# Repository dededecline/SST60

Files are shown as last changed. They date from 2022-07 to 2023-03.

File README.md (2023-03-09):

# SST60

## Hotswap
Looking for hotswap? See [here](https://github.com/dededecline/SST60/tree/main/Hotswap)

## Fully open source multi-layout 60% PCB
Render1
Render2
<sub> renders outdated, using the old outline. </sub>

## Layout support
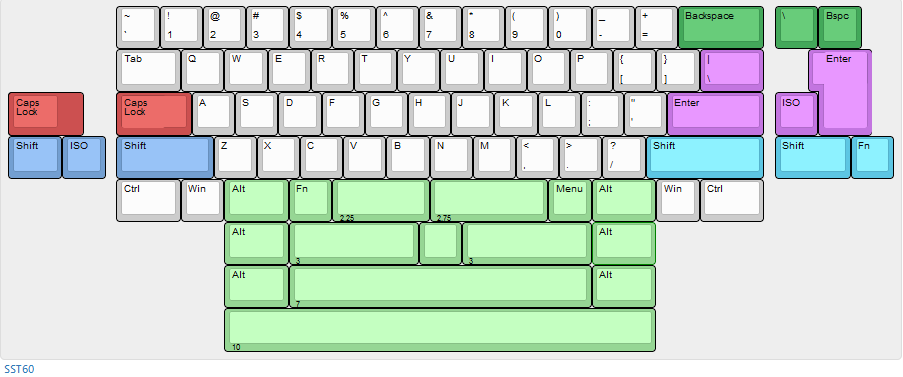
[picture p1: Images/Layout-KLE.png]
KLE


## Features
- RGB Underglow
- RP2040 processor
- MX and Alps compatible
- Indicator light positions for Caps Lock and Esc
- Standard tray mount support
- Gummy O-Ring support (Bakenko, ogre, etc. anything that h60 supports, this does too.)
- USB-C or Unified Daughterboard (or equivalent with the same pinout)
- Overcurrent and ESD protection
- Flex meme cuts

## ***DISCLAIMER***
This PCB has been tested and confirmed to work properly. The members of the PCB development team are not liable if you end up with a non-functional pcb. Order at your own risk. Support will not be provided but pull requests will be reviewed and possibly accepted.

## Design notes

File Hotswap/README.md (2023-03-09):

# SST60HS

## Fully open source multi-layout 60% PCB
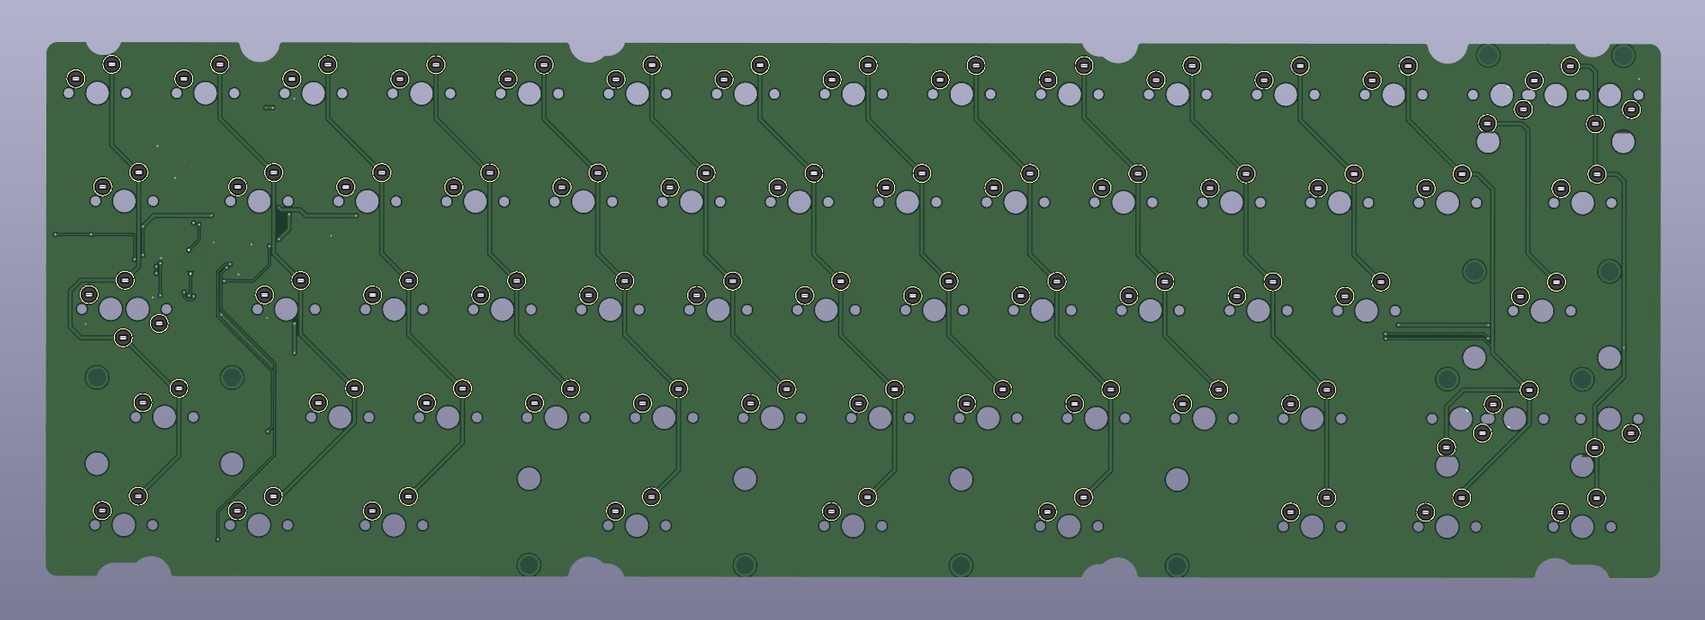
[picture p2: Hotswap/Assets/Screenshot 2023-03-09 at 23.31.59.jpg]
render


## Layout support
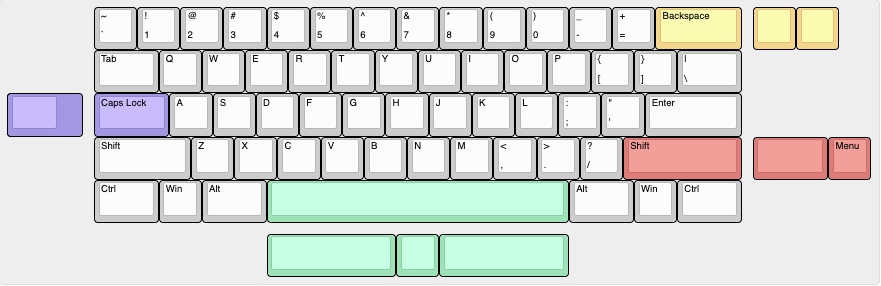
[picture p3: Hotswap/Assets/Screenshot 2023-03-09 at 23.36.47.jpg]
KLE


## Features
- RP2040 processor
- Hotswap
- Gummy O-Ring support (Bakeneko v2, Ogre. NOTE: Does not support Kei, missing the big cuts due to interference with the sockets)
- Unified Daughterboard C4/S1 support (or equivalent with the same pinout and EZmate connector)
- Overcurrent and ESD protection

## ***DISCLAIMER***
This PCB has been tested and confirmed to work properly. The members of the PCB development team are not liable if you end up with a non-functional pcb. Order at your own risk. Support will not be provided but pull requests will be reviewed and possibly accepted.

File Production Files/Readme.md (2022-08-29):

# Production
- Files ready for jlcpcb production.
- Choose between USB or Daughterboard version, same gerber zip for both.

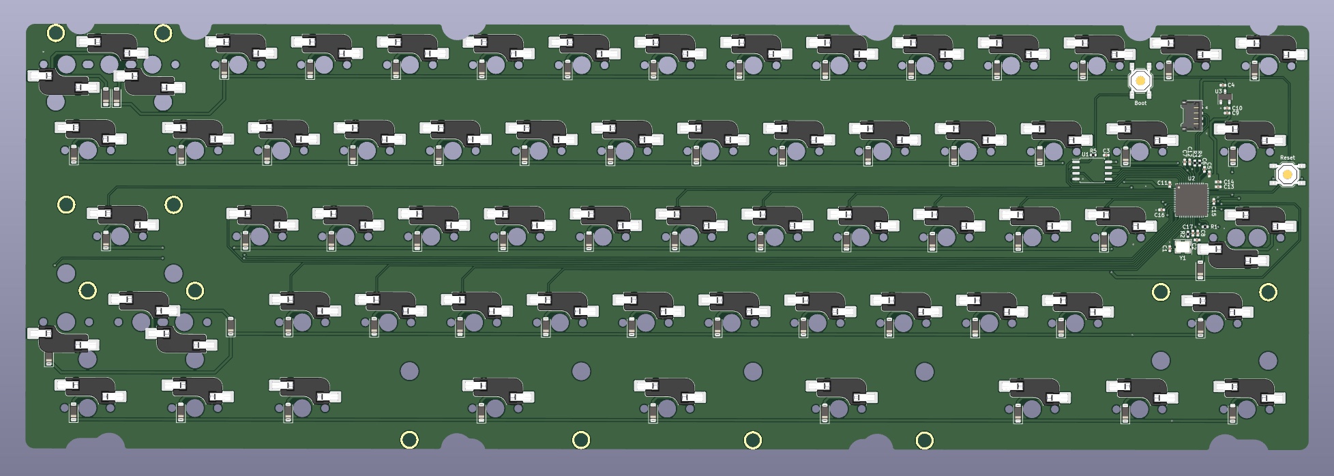
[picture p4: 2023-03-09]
Hotswap/Assets/Screenshot 2023-03-09 at 23.32.19.jpg

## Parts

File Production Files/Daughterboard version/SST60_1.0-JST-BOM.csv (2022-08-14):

Comment | Designator | Footprint | LCSC
1k | R_Crystal1,R_Flash1,R_RST1 | R_0402_1005Metric | C11702
SM04B | J1 | JST_SH_SM04B-SRSS-TB_1x04-1MP_P1.00mm_Horizontal | C145956
.1u | C_1V-Decoup2,C_1V-Decoup3,C_3V-Decoup3,C_3V-Decoup4,C_3V-Decoup5,C_3V-Decoup6,C_3V-Decoup7,C_3V-Decoup8,C_3V-Decoup9,C_Flash1 | C_0402_1005Metric | C1525
10u | C_3V-Decoup1 | C_0402_1005Metric | C15525
22pF | C_Crystal1,C_Crystal2 | C_0402_1005Metric | C1555
RP2040 | U1 | RP2040-QFN-56 | C2040
220 | R_LED1,R_LED2 | R_0402_1005Metric | C25091
27 | R_DATA1,R_DATA2 | R_0402_1005Metric | C25100
Boot | SW1,SW2 | SW_SPST_TL3342 | C318884
1u | C_1V-Decoup1,C_3V-Decoup2,C_LDO1,C_LDO2 | C_0402_1005Metric | C52923
XC6206PxxxMR | U3 | SOT-23 | C5446
D_Small | D1,D10,D11,D12,D13,D14,D15,D16,D17,D18,D19,D2,D20,D21,D22,D23,D24,D25,D26,D27,D28,D29,D3,D30,D31,D32,D33,D34,D35,D36,D37,D38,D39,D4,D40,D41,D42,D43,D44,D45,D46,D47,D48,D49,D5,D50,D51,D52,D53,D54,D55,D56,D57,D58,D59,D6,D60,D61,D62,D63,D64,D65,D66,D67,D68,D7,D8,D9 | D_SOD-123 | C64898
74AHCT1G125 | U5 | SOT-23-5 | C7468
12MHz | Y1 | Crystal_SMD_3225-4Pin_3.2x2.5mm | C9002
WS2812B-2020 | D69,D70,D71,D72,D73,D74,D75,D76,D77,D78,D79,D80,D81,D82,D83,D84 | LED_WS2812_2020 | C965555
W25Q128JVS | U2 | SOIC-8_5.23x5.23mm_P1.27mm | C97521

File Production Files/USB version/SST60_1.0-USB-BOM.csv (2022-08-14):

Comment | Designator | Footprint | LCSC
1k | R_Crystal1,R_Flash1,R_RST1 | R_0402_1005Metric | C11702
PRTR5V0U2X | U4 | SOT143B | C12333
.1u | C_1V-Decoup2,C_1V-Decoup3,C_3V-Decoup3,C_3V-Decoup4,C_3V-Decoup5,C_3V-Decoup6,C_3V-Decoup7,C_3V-Decoup8,C_3V-Decoup9,C_Flash1 | C_0402_1005Metric | C1525
4.7n | C_Shield1 | C_0402_1005Metric | C1538
10u | C_3V-Decoup1 | C_0402_1005Metric | C15525
22pF | C_Crystal1,C_Crystal2 | C_0402_1005Metric | C1555
HRO-TYPE-C-31-M-12 | USB1 | HRO-TYPE-C-31-M-12-Assembly | C165948
RP2040 | U1 | RP2040-QFN-56 | C2040
220 | R_LED1,R_LED2 | R_0402_1005Metric | C25091
27 | R_DATA1,R_DATA2 | R_0402_1005Metric | C25100
5k1 | R_USB1,R_USB2 | R_0402_1005Metric | C25905
1M | R_Shield1 | R_0402_1005Metric | C26083
Boot | SW1,SW2 | SW_SPST_TL3342 | C318884
1u | C_1V-Decoup1,C_3V-Decoup2,C_LDO1,C_LDO2 | C_0402_1005Metric | C52923
XC6206PxxxMR | U3 | SOT-23 | C5446
D_Small | D1,D10,D11,D12,D13,D14,D15,D16,D17,D18,D19,D2,D20,D21,D22,D23,D24,D25,D26,D27,D28,D29,D3,D30,D31,D32,D33,D34,D35,D36,D37,D38,D39,D4,D40,D41,D42,D43,D44,D45,D46,D47,D48,D49,D5,D50,D51,D52,D53,D54,D55,D56,D57,D58,D59,D6,D60,D61,D62,D63,D64,D65,D66,D67,D68,D7,D8,D9 | D_SOD-123 | C64898
74AHCT1G125 | U5 | SOT-23-5 | C7468
500mA | F1 | Fuse_0805_2012Metric | C883103
12MHz | Y1 | Crystal_SMD_3225-4Pin_3.2x2.5mm | C9002
WS2812B-2020 | D69,D70,D71,D72,D73,D74,D75,D76,D77,D78,D79,D80,D81,D82,D83,D84 | LED_WS2812_2020 | C965555
W25Q128JVS | U2 | SOIC-8_5.23x5.23mm_P1.27mm | C97521

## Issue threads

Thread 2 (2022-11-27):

Future MCU support

ojthetiny, 2022-11-27:
With the Raspberry Pi Foundation having angered broadcom with the release of RP2040 and the [troubling signs regarding the chips future](https://www.jeffgeerling.com/blog/2022/you-cant-buy-raspberry-pi-right-now), it might be wise to look into developing an STM32 based variant of the PCB.

The STM32F072C8T6 being priced at only $2.4 on LCSC and having a good bit of stock available, it might be a worthwhile option to look into, should be a bit cheaper than the RP2040 version due to less required components.

Likely won't be replacing the main project, but something on another backup branch to ensure the PCB not becoming obsolete in the future?

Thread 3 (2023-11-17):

Not working when connected to iPad

Babyyoda777, 2023-11-17:
Made the hotswap version and works beautifully with my laptop. However I connect to iPad and whilst it detects the keyboard correctly, nothing works and iPad receives no input. Using C to C cable on 2022 iPad Pro, any ideas why?

Closed 2023-11-17.

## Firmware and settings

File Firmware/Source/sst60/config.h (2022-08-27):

/*
Copyright 2022 ojthetiny

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
You should have received a copy of the GNU General Public License
along with this program.  If not, see <http://www.gnu.org/licenses/>.
*/

#pragma once

#include "config_common.h"


/* USB Device descriptor parameter */
#define VENDOR_ID       0x6F6A
#define PRODUCT_ID      0x5336
#define DEVICE_VER      0x0001
#define MANUFACTURER    ojthetiny
#define PRODUCT         sst60


/* key matrix size */
#define MATRIX_ROWS 5
#define MATRIX_COLS 15

#define DEBUG_MATRIX_SCAN_RATE
#define DEBUG_ACTION

/* key matrix pins */
#define MATRIX_ROW_PINS { GP28, GP27, GP20, GP6, GP7 }
#define MATRIX_COL_PINS { GP21, GP5, GP4, GP3, GP2, GP1, GP0, GP15, GP14, GP13, GP12, GP11, GP10, GP8, GP9 }
#define UNUSED_PINS

/* COL2ROW or ROW2COL */
#define DIODE_DIRECTION COL2ROW

/* Set 0 if debouncing isn't needed */
#define DEBOUNCE 5

/* number of backlight levels */


#define RGB_DI_PIN GP29
#define DRIVER_LED_TOTAL 16
#define RGBLED_NUM 16
#define RGBLIGHT_LIMIT_VAL 173

#define ENABLE_RGB_MATRIX_ALPHAS_MODS
#define ENABLE_RGB_MATRIX_GRADIENT_UP_DOWN
#define ENABLE_RGB_MATRIX_GRADIENT_LEFT_RIGHT
#define ENABLE_RGB_MATRIX_BREATHING
#define ENABLE_RGB_MATRIX_BAND_SAT
#define ENABLE_RGB_MATRIX_BAND_VAL
#define ENABLE_RGB_MATRIX_BAND_PINWHEEL_SAT
#define ENABLE_RGB_MATRIX_BAND_PINWHEEL_VAL
#define ENABLE_RGB_MATRIX_BAND_SPIRAL_SAT
#define ENABLE_RGB_MATRIX_BAND_SPIRAL_VAL
#define ENABLE_RGB_MATRIX_CYCLE_ALL
#define ENABLE_RGB_MATRIX_CYCLE_LEFT_RIGHT
#define ENABLE_RGB_MATRIX_CYCLE_UP_DOWN
#define ENABLE_RGB_MATRIX_RAINBOW_MOVING_CHEVRON
#define ENABLE_RGB_MATRIX_CYCLE_OUT_IN
#define ENABLE_RGB_MATRIX_CYCLE_OUT_IN_DUAL
#define ENABLE_RGB_MATRIX_CYCLE_PINWHEEL
#define ENABLE_RGB_MATRIX_CYCLE_SPIRAL
#define ENABLE_RGB_MATRIX_DUAL_BEACON
#define ENABLE_RGB_MATRIX_RAINBOW_BEACON
#define ENABLE_RGB_MATRIX_RAINBOW_PINWHEELS
// enabled only if RGB_MATRIX_FRAMEBUFFER_EFFECTS is defined
#define ENABLE_RGB_MATRIX_TYPING_HEATMAP
#define ENABLE_RGB_MATRIX_DIGITAL_RAIN
// enabled only of RGB_MATRIX_KEYPRESSES or RGB_MATRIX_KEYRELEASES is defined
#define ENABLE_RGB_MATRIX_SOLID_REACTIVE_SIMPLE
#define ENABLE_RGB_MATRIX_SOLID_REACTIVE
#define ENABLE_RGB_MATRIX_SOLID_REACTIVE_WIDE
#define ENABLE_RGB_MATRIX_SOLID_REACTIVE_MULTIWIDE
#define ENABLE_RGB_MATRIX_SOLID_REACTIVE_CROSS
#define ENABLE_RGB_MATRIX_SOLID_REACTIVE_MULTICROSS
#define ENABLE_RGB_MATRIX_SOLID_REACTIVE_NEXUS
#define ENABLE_RGB_MATRIX_SOLID_REACTIVE_MULTINEXUS
#define ENABLE_RGB_MATRIX_SPLASH
#define ENABLE_RGB_MATRIX_MULTISPLASH
#define ENABLE_RGB_MATRIX_SOLID_SPLASH
#define ENABLE_RGB_MATRIX_SOLID_MULTISPLASH
#define RGB_DISABLE_WHEN_USB_SUSPENDED
#define RGB_MATRIX_KEYPRESSES

#define VIA_CUSTOM_LIGHTING_ENABLE

#define LED_CAPS_LOCK_PIN GP17
#define LED_KANA_PIN GP26
#define LED_PIN_ON_STATE 1

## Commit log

2022-07-27 Initial Commit
    Massive file dump
    [MCU.kicad_sch, Misc.kicad_sch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]
2022-07-27 Fixed pcb outline
    it did not have bakeneko support, now it does :)
    [SST60-B_Cu.gbl, SST60-B_Mask.gbs, SST60-B_Paste.gbp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]
2022-07-27 update readme
    updated readme to reflect pcb outline changes
2022-07-27 Update pcb step
    updated pcb step file to reflect the changes to the pcb outline
2022-07-31 Fixed BD version production files
    rotated a few components around in the pos file
    [SST60_0.1-JST-POS.csv]
2022-07-31 Tray mount fix
    Solved potential ground loop issue with the tray mount points. Only one point is connected to Ground
    [SST60-B_Cu.gbl, SST60-B_Mask.gbs, SST60-B_Paste.gbp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]
2022-07-31 rotate LEDs in production file
    re-fixing the jst versions POS file; rotate LEDs to the correct orientation
    [SST60_0.1-JST-POS.csv]
2022-08-01 fixed LED routing error
    LED 3v3 traces were cut as a result of hasty outline change without thinking properly. fixed those
    [MCU.kicad_sch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]
2022-08-01 something
    pcbnew save for... something?
2022-08-14 QoL Improvements
    - Add physical button for Bootloader and Reset.
    - Add logic level shifter for the leds according to suggestion by Sleepdealer.
    [MCU.kicad_sch, Misc.kicad_sch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]
2022-08-27 Update README.md
    Confirmed that PCB has been tested.
2022-08-29 Updated LED wiring. Changed production file version scheme.
    [Misc.kicad_sch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]
2023-03-09 Add Hotswap version
    [SST60HS-BOM.csv, SST60HS.kicad_sch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]
2023-04-25 fix diode placement in hotswap version
    [SST60HS-POS.csv]

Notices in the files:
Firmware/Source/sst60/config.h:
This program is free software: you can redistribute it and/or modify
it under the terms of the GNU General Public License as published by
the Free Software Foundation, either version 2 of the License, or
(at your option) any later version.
